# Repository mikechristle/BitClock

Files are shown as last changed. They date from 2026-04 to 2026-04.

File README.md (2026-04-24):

# BitClock
How can I display the time. Let me count the ways.  

Over the years I have built several clock projects to display the time in interesting ways.
Most have had limited success because of the challenge of keeping accurate time.
This clock uses a Raspberry Pi Pico W to get the correct time over the internet.
This is definitely overkill for a clock, but at $6 I said why not.
## Overview
A clock that displays the time in binary.  
  
The display has three rows of four LEDs.
The top row displays the hour, 1 to 12.
The middle row displays the tens of minutes, 0 to 5.
The bottom row displays the ones of minutes, 0 to 9.  

The clock has a buzzer to play a song for an alarm.
To set the alarm time, use the PC Control Program.
## Code
The BitClock is controlled by a Raspberry Pi Pico W.
All the code is written in Micro-Python.
The code will get the current time over the internet using the get_ntp_time library.

The file network.info contains the login credentials for you router.
When the clock powers up, it will use this info to login, 
then display the last byte of the IP address for 10 seconds.
This address is needed in the PS control program to connect to the clock.
## PC Control Program
The control program was written in Python.
It runs on a PC and communicates with the clock with a socket connection.
I tested is on Windows, since it is Python it should run on Apple and Linux.
This program will allow you to set the alarm, set the time zone,
and adjust the LED brightness.
## PCB
The PCB was designed in KiCad version 10.0.1.
It is a two layer board.
All of the symbol and footprints are included in the local definition files.

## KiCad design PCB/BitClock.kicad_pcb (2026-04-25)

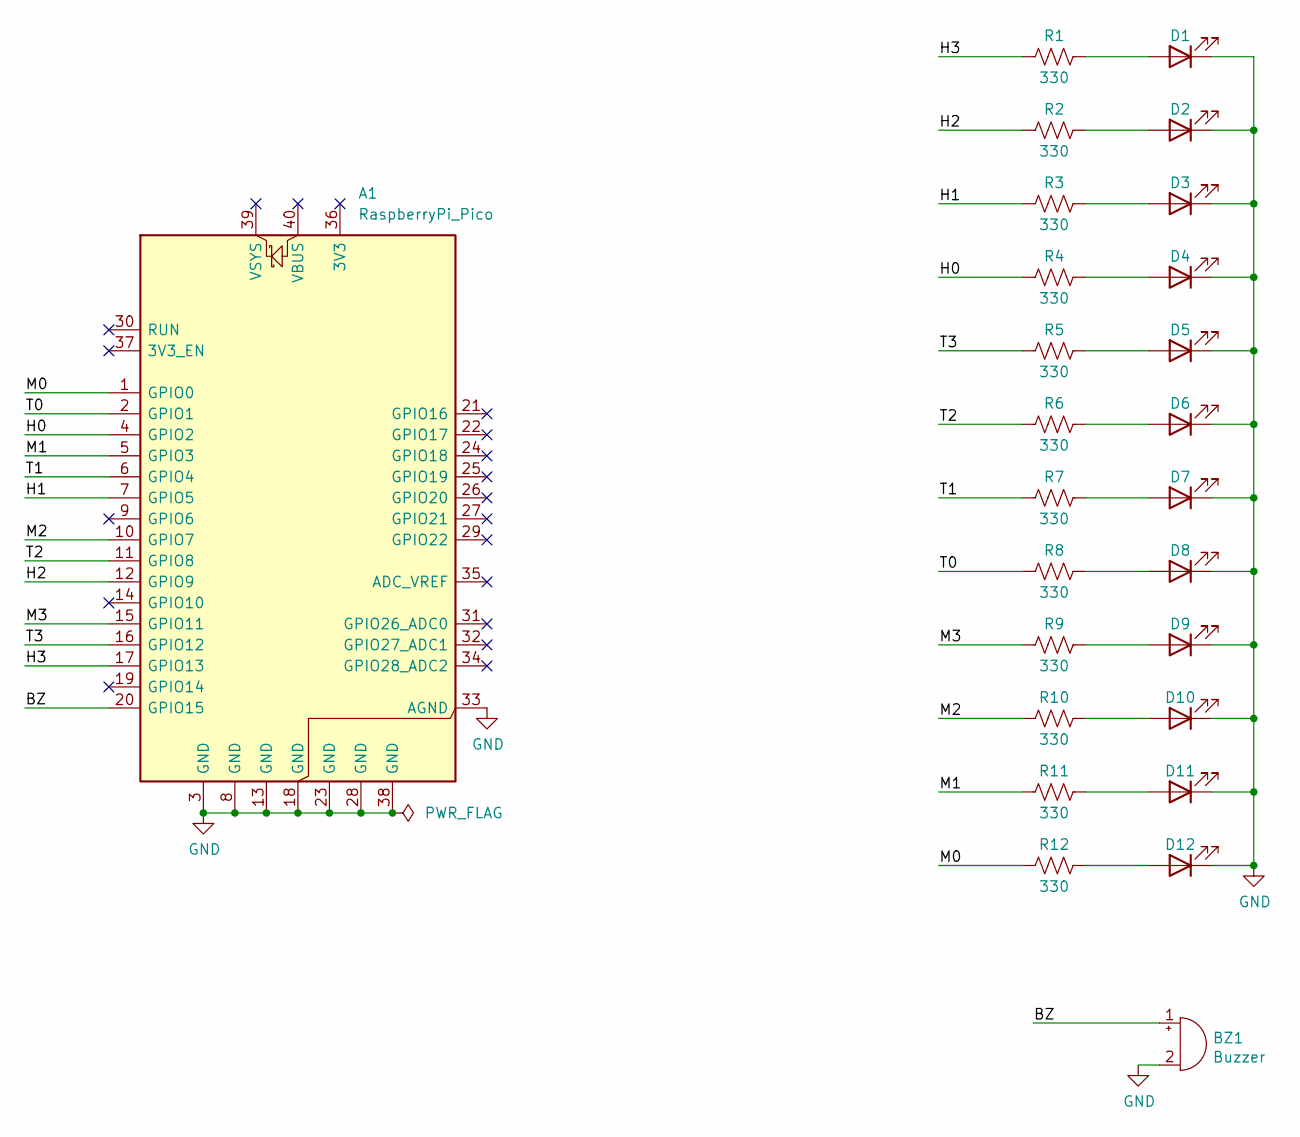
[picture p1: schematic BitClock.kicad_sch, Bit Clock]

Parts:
A1: RaspberryPi_Pico; DIP-40_700_ELL
BZ1: Buzzer; Buzzer_D14mm_H7mm_P10mm
D1, D2, D3, D4, D5, D6, D7, D8, D9, D10, D11, D12: LED; LED_D8.0mm
R1, R2, R3, R4, R5, R6, R7, R8, R9, R10, R11, R12: 330; R_Axial_DIN0204_L3.6mm_D1.6mm_P5.08mm_Horizontal

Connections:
/BZ: A1.20 (GPIO15), BZ1.1 (+)
/H0: A1.4 (GPIO2), R4.2
/H1: A1.7 (GPIO5), R3.2
/H2: A1.12 (GPIO9), R2.2
/H3: A1.17 (GPIO13), R1.2
/M0: A1.1 (GPIO0), R12.2
/M1: A1.5 (GPIO3), R11.2
/M2: A1.10 (GPIO7), R10.2
/M3: A1.15 (GPIO11), R9.2
/T0: A1.2 (GPIO1), R8.2
/T1: A1.6 (GPIO4), R7.2
/T2: A1.11 (GPIO8), R6.2
/T3: A1.16 (GPIO12), R5.2
GND: A1.3 (GND), A1.8 (GND), A1.13 (GND), A1.18 (GND), A1.23 (GND), A1.28 (GND), A1.33 (AGND), A1.38 (GND), BZ1.2 (-), D1.1 (K), D2.1 (K), D3.1 (K), D4.1 (K), D5.1 (K), D6.1 (K), D7.1 (K), D8.1 (K), D9.1 (K), D10.1 (K), D11.1 (K), D12.1 (K)
unnamed: D1.2 (A), R1.1
unnamed: D2.2 (A), R2.1
unnamed: D3.2 (A), R3.1
unnamed: D4.2 (A), R4.1
unnamed: D5.2 (A), R5.1
unnamed: D6.2 (A), R6.1
unnamed: D7.2 (A), R7.1
unnamed: D8.2 (A), R8.1
unnamed: D9.2 (A), R9.1
unnamed: D10.2 (A), R10.1
unnamed: D11.2 (A), R11.1
unnamed: D12.2 (A), R12.1

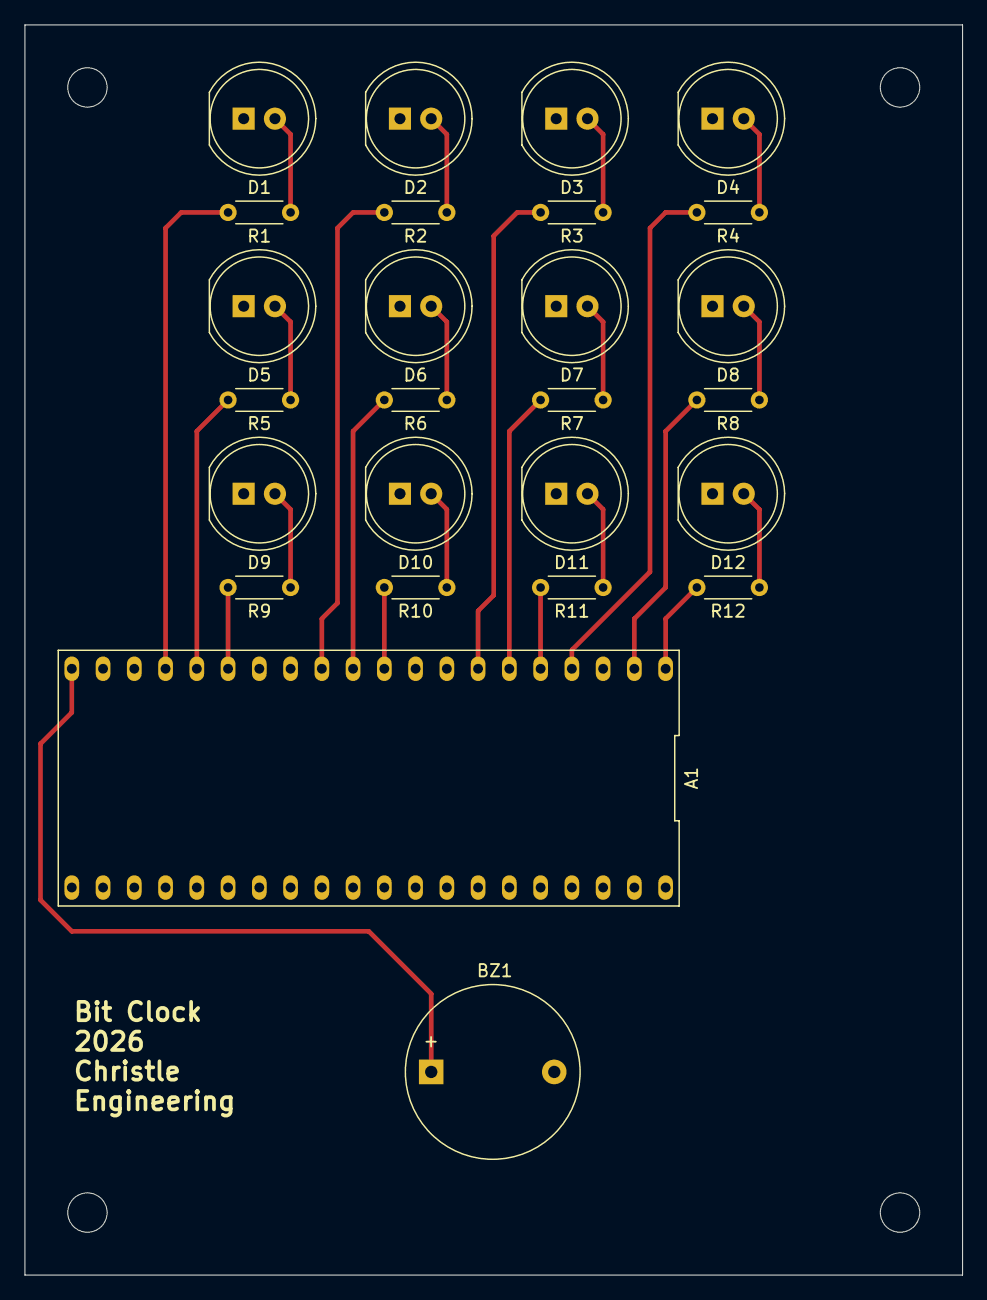
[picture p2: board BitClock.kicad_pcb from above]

Board: 2 copper layers, 76.2 x 101.6 mm, 26 parts (0 on the bottom side), 26 nets.

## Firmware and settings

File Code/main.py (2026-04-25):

# ---------------------------------------------------------------------
# Bit Clock
# Mike Christle 2024
# ---------------------------------------------------------------------

from network import WLAN, STA_IF
from socket import socket
from machine import Timer, PWM, Pin, RTC
from time import sleep, localtime, gmtime
from get_ntp_time import get_ntp_time

import music_player as mp


PATTERNS = (
    (0xFFF, 0x000),
    (0x333, 0xCCC),
    (0xFFF, 0x000),
    (0x333, 0xCCC),
    (0xFFF, 0x000),
    (0x333, 0xCCC),
    (0xFFF, 0x000),
    (0x333, 0xCCC),
)

SONG = (
    (mp.G4, mp.QN), (mp.G4, mp.QN), (mp.G4, mp.QN), (mp.A4, mp.QN),
    (mp.B4, mp.HN), (mp.G4, mp.HN),
    (mp.D5, mp.QN), (mp.D5, mp.QN), (mp.D5, mp.QN), (mp.E5, mp.QN),
    (mp.D5, mp.WN),
    (mp.D5, mp.QN), (mp.E5, mp.QN), (mp.D5, mp.QN), (mp.C5, mp.QN),
    (mp.B4, mp.HN), (mp.G4, mp.HN),
    (mp.A4, mp.QN), (mp.C5, mp.QN), (mp.B4, mp.QN), (mp.A4, mp.QN),
    (mp.G4, mp.WN),
)

player = mp.MusicPlayer(15)

minute = -1
hour = -1

alarm_hr = -1
alarm_mn = 0
alarm_state = 0

bright0 = 600
bright1 = 32000

clock_timer = Timer()
anima_timer = Timer()

h0 = PWM(Pin(2), freq=500, duty_u16=0)
h1 = PWM(Pin(5), freq=500, duty_u16=0)
h2 = PWM(Pin(9), freq=500, duty_u16=0)
h3 = PWM(Pin(13), freq=500, duty_u16=0)
t0 = PWM(Pin(1), freq=500, duty_u16=0)
t1 = PWM(Pin(4), freq=500, duty_u16=0)
t2 = PWM(Pin(8), freq=500, duty_u16=0)
t3 = PWM(Pin(12), freq=500, duty_u16=0)
m0 = PWM(Pin(0), freq=500, duty_u16=0)
m1 = PWM(Pin(3), freq=500, duty_u16=0)
m2 = PWM(Pin(7), freq=500, duty_u16=0)
m3 = PWM(Pin(11), freq=500, duty_u16=0)

# ---------------------------------------------------------------------
# Update the time
# ---------------------------------------------------------------------
def check_time(timer):
    global hour, minute, alarm_state, alarm_hr, alarm_mn

    t = localtime()
    if t[4] != minute:
        if hour == 3 and minute == 41:
            set_time()
            t = localtime()

        hour = t[3]
        minute = t[4]
        update_display(hour, minute)

        if hour == alarm_hr and minute == alarm_mn:
            animation_init()
            player.play(SONG, 192, mp.QN, 3)
            alarm_hr = alarm_mn = -1


# ---------------------------------------------------------------------
def animation_init():
    global pats_idx, pat_idx, pat_cnt

    pats_idx = 0
    pat_idx = 0
    pat_cnt = 0
    anima_timer.init(period=200, callback=animation)


# ---------------------------------------------------------------------
def animation(_):
    global pats_idx, pat_idx, pat_cnt

    pats = PATTERNS[pats_idx]
    pat = pats[pat_idx]
    h = pat >> 8
    t = (pat >> 4) & 15
    m = pat & 15
    write_display(h, t, m)
    pat_idx += 1
    if pat_idx >= len(pats):
        pat_idx = 0
        pat_cnt += 1
        if pat_cnt >= 10:
            pat_cnt = 0
            pats_idx += 1
            if pats_idx >= len(PATTERNS):
                anima_timer.deinit()
                update_display(hour, minute)


# ---------------------------------------------------------------------
def update_display(h, m):

#     print(f'{h:02}:{m:02}')
    t = m // 10
    m = m % 10
    h = h - 12 if h > 12 else h
    h = 12 if h == 0 else h
    write_display(h, t, m)


# ---------------------------------------------------------------------
def write_display(h, t, m):

    pw = bright0 if (m & 1) == 0 else bright1
    m0.duty_u16(pw)
    pw = bright0 if (m & 2) == 0 else bright1
    m1.duty_u16(pw)
    pw = bright0 if (m & 4) == 0 else bright1
    m2.duty_u16(pw)
    pw = bright0 if (m & 8) == 0 else bright1
    m3.duty_u16(pw)
        
    pw = bright0 if (t & 1) == 0 else bright1
    t0.duty_u16(pw)
    pw = bright0 if (t & 2) == 0 else bright1
    t1.duty_u16(pw)
    pw = bright0 if (t & 4) == 0 else bright1
    t2.duty_u16(pw)
    pw = bright0 if (t & 8) == 0 else bright1
    t3.duty_u16(pw)
    
    pw = bright0 if (h & 1) == 0 else bright1
    h0.duty_u16(pw)
    pw = bright0 if (h & 2) == 0 else bright1
    h1.duty_u16(pw)
    pw = bright0 if (h & 4) == 0 else bright1
    h2.duty_u16(pw)
    pw = bright0 if (h & 8) == 0 else bright1
    h3.duty_u16(pw)


# ---------------------------------------------------------------------
def set_time():
    global hour, minute

    # Get the time zone
    with open('time_zone.txt', 'rt') as ifp:
        offset = ifp.read()

    # Get the current URC time
    get_ntp_time(int(offset))

    # Display Time
    dt = localtime()
    update_display(dt[4], dt[5])
    print(dt)


# ---------------------------------------------------------------------
# Setup internet connection
# ---------------------------------------------------------------------

with open("login.txt", "r") as file:
    SSID = file.readline().strip()
    PSWD = file.readline().strip()

wlan = WLAN(STA_IF)
wlan.active(True)
wlan.connect(SSID, PSWD)
while wlan.isconnected() == False:
    print('Waiting for connection...')
    sleep(1)

ip = wlan.ifconfig()[0]
print(ip)

# Display the IP address LSB
idx = ip.rfind('.')
ip3 = int(ip[idx + 1:])
update_display(ip3 // 100, ip3 % 100)
sleep(10.0)

# Open socket receiver
conn = socket()
conn.bind((ip, 23))
conn.listen()

# Get the current time
set_time()

# Start the clock timer
clock_timer.init(freq=0.2, callback=check_time)

# Main loop to wait for input connection
while True:

    try:
        client = conn.accept()[0]
        while True:
            msg = client.recv(1024).decode("utf-8")
            print(msg)

            # Close Connection
            if msg == 'bye':
                break

            # Set One Brightness
            if msg[:2] == 'b1':
                bright1 = int(msg[2:]) * 650
                client.send('OK')
                update_display(hour, minute)

            # Set Zero Brightness
            elif msg[:2] == 'b0':
                bright0 = int(msg[2:]) * 650
                client.send('OK')
                update_display(hour, minute)

            # Get Alarm Time
            elif msg[:2] == 'ga':
                client.send(f'{alarm_hr:02}:{alarm_mn:02}')

            # Get Time
            elif msg[:2] == 'gt':
                client.send(f'{hour:02}:{minute:02}')

            # Get Time Zone Offset
            elif msg[:2] == 'gz':
                with open('time_zone.txt','rt') as ifp:
                    tz = ifp.read()
                client.send(tz)

            # Set Time Zone Offset
            elif msg[:2] == 'sz':
                with open('time_zone.txt','wt') as ofp:
                    ofp.write(msg[2:])
                set_time()
                client.send('OK')

            # Set Alarm Time
            elif msg[:2] == 'sa':
                idx = msg.find(':')
                alarm_hr = int(msg[2:idx])
                alarm_mn = int(msg[idx + 1:])
                client.send('OK')

            # Anything else is an error
            else:
                client.send('ERROR')

        client.close()
        print('here 3')
    except Exception as e:
        ct = localtime()
        ts = f'{ct[0]}/{ct[1]}/{ct[2]}  {ct[3]}:{ct[4]}\n'
        print(f'Error: {e}')
        with open('error.txt', 'a') as ofp:
            ofp.write(f'MainLoop: {e}\n{ts}\n\n')
        client.close()

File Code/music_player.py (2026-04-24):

# ---------------------------------------------------------------------------
# Music Player
# Mike Christle 2024
# ---------------------------------------------------------------------------

from micropython import const
from machine import mem32, Pin, PWM, Timer
from time import sleep


# Duration
SN = 1   # Sixteenth Note
EN = 2   # Eighth Note
QN = 4   # Quarter Note
HN = 8   # Half Note
WN = 16  # Whole Note

# Pitch
C3  = 287, 53273
C3S = 545, 26479
D3  = 665, 20483
D3S = 237, 54248
E3  = 274, 44289
F3  = 175, 65452
F3S = 170, 63593
G3  = 259, 39398
G3S = 223, 43191
A3  = 219, 41511
A3S = 148, 57978
B3  = 227, 35679
C4  = 2573, 2971
C4S = 769, 9383
D4  = 281, 24237
D4S = 201, 31981
E4  = 148, 40996
F4  = 95, 60283
F3S = 851, 6352
G4  = 259, 19699
G4S = 133, 36209
A4  = 281, 16176
A4S = 74, 57978
B4  = 1163, 3482
C5  = 3623, 1055
C5S = 1709, 2111
D5  = 83, 41027
D5S = 62, 51841
E5  = 74, 40996
F5  = 347, 8252
F5S = 111, 24349
G5  = 62, 41146
G5S = 193, 12476
A5  = 281, 8088
A5S = 46, 46634
B5  = 193, 10491

# Register Base Addresses
REG_BASE = const(0x40050000)
IO_BASE  = const(0x40014004)


class MusicPlayer:

    def __init__(self, gpio):
        pin_cntl = IO_BASE + (gpio * 8)
        mem32[pin_cntl] = 0x04

        self.shift = 0 if (gpio & 1) == 0 else 16
        gpio = (gpio & 15) >> 1
        self.reg_csr = REG_BASE + (gpio * 0x14)
        self.reg_div = REG_BASE + (gpio * 0x14) + 4
        self.reg_cc  = REG_BASE + (gpio * 0x14) + 12
        self.reg_top = REG_BASE + (gpio * 0x14) + 16

        self.timer = Timer()
        self.tune = None
        self.tune_idx = 0
        self.loop_cntr = 0
        self.beat_cntr = 0
        self.done = True

    def play(self, tune, bpm, beat_note, loops = 1):
        self.done = False
        beat_time = (60 / bpm / beat_note) * 1000

        self.tune = tune
        self.tune_idx = 0
        self.beat_cntr = 0
        self.loop_cntr = loops
        self.timer.init(mode=Timer.PERIODIC,
                        period=int(beat_time),
                        callback=self.worker)

    def worker(self, _):

        if self.beat_cntr > 0:
            self.beat_cntr -= 1
            return

        mem32[self.reg_csr] = 0
        if self.tune_idx >= len(self.tune):
            self.loop_cntr -= 1
            if self.loop_cntr == 0:
                self.timer.deinit()
                self.done = True
                return
            else:
                self.tune_idx = 0

        note, self.beat_cntr = self.tune[self.tune_idx]
        div, top = note
        mem32[self.reg_div] = div
        mem32[self.reg_top] = top
        mem32[self.reg_cc] = (top // 2) << self.shift
        mem32[self.reg_csr] = 1
        self.tune_idx += 1


if __name__ == "__main__":
    DO_RA_ME = ((C4, QN), (D4, QN), (E4, QN), (F4, QN), (G4, QN), (A4, QN), (B4, QN), (C5, QN))
    mp = MusicPlayer(0)
    mp.play(DO_RA_ME, 192, QN, 2)
    while not mp.done:
        pass
